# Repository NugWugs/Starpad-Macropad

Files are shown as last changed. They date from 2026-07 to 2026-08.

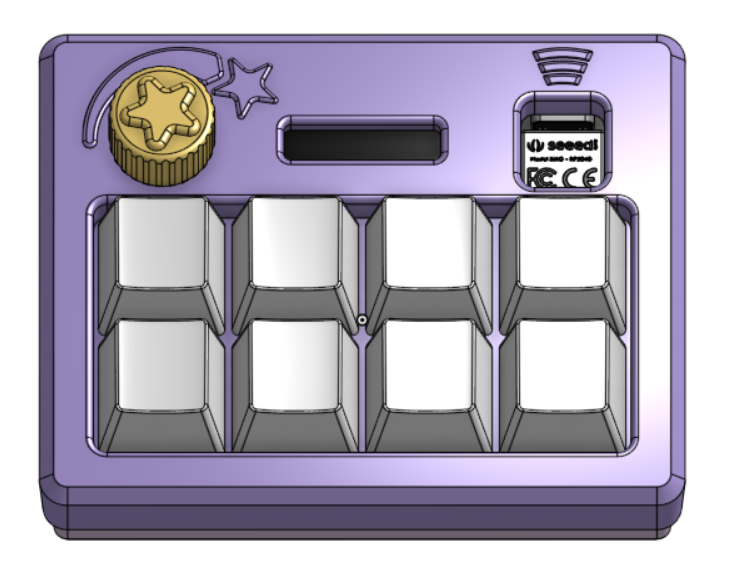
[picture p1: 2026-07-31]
starpad_v1/assets/img.png

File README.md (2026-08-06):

## Components:
- 4x2 Macropad Layout
- 1 Encoder Switch
- 1 0.91" 128x32 OLED Display
- Seeed Studio XIAO RP2040

## Function:
- Keys are programmed to hotkeys for different purposes
- Rotation of encoder changes volume
- Pressing of encoder switches between sets of hotkeys
- OLED displays selected hotkey set

## Onshape Link (CAD): 
https://cad.onshape.com/documents/8be66bb81c9edfabe40a1824/w/8ff97f5b07f3c9e6564f80fb/e/1183bdaa753b085b3b18a6f9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

## CAD:

<p align="left">
  isometric
  top
</p>

## PCB:
<p align="left">
  schematic
  pcb_routing
  pcb_top
</p>

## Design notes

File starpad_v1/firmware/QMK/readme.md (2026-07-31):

# XIAO RP2040 Macropad (QMK)

Custom QMK keyboard for a Seeed XIAO RP2040 driving a 4x2 button matrix
(SW1-SW8), a rotary encoder + push-switch (SW12), and an SSD1306 0.91"
128x32 I2C OLED (U2).

## Pin map (from schematic, D-number -> GPIO)

| Signal | XIAO pin | GPIO  |
|---|---|---|
| Col1 | D0 | GP26  |
| Col2 | D1 | GP27  |
| Col3 | D2 | GP28  |
| Col4 | D3 | GP29  |
| Row1 | D8 | GP2 |
| Row2 | D7 | GP1 |
| RotA | D9 | GP4 |
| RotB | D10 | GP3 |
| RotEnc | D6 | GP0 |
| SDA | D4 | GP6 |
| SCL | D5 | GP7 |

## Why a custom matrix.c

The schematic's diodes conduct **column -> row** (anode at the switch,
cathode toward the row net). QMK's stock `COL2ROW` scanner assumes the
opposite electrical polarity (idle-HIGH columns pulled briefly LOW,
rows pulled up and read LOW-for-pressed). To match your actual wiring,
`matrix.c` drives columns idle-LOW / active-HIGH and reads rows as
pulled-down / HIGH-for-pressed.

It also reads the encoder's push-switch (a plain switch-to-GND, no
diode) as a 9th key at matrix position `(row 2, col 0)`. Columns 1-3 of
row 2 don't physically exist and are left unmapped (`KC_NO` in the
keymap, though the default keymap only defines `KC_MUTE` at that one
real position).

**Double-check on the bench**: if the 8 main keys don't respond, or
respond only while held opposite of expected, the diode reading may be
backwards from what's on your schematic — flip the row read logic in
`matrix_scan_custom()` (swap `HIGH`/pull-down for `LOW`/pull-up) to
match.

## Build & flash

1. Drop this whole `xiao_rp2040_macropad` folder into
   `qmk_firmware/keyboards/`.
2. From the `qmk_firmware` root:
   ```
   qmk compile -kb xiao_rp2040_macropad -km default
   ```
3. Put the XIAO RP2040 into bootloader mode (double-tap the RESET
   button, or hold BOOTSEL while plugging in) — it will mount as a USB
   drive named `RPI-RP2`.
4. Copy the generated `.uf2` file (in
   `qmk_firmware/.build/`) onto that drive. The board reboots
   automatically running the new firmware.

## Customizing

- **Keymap**: edit `keymaps/default/keymap.c` — swap `KC_1`..`KC_8` for
  whatever keycodes/macros you actually want.
- **Encoder action**: `encoder_update_user()` in the same file currently
  does volume up/down; change it to anything else (media, custom
  layers, RGB, etc).
- **OLED content**: `oled_task_user()` currently just prints a static
  label — replace with layer indicators, WPM, encoder value, etc.

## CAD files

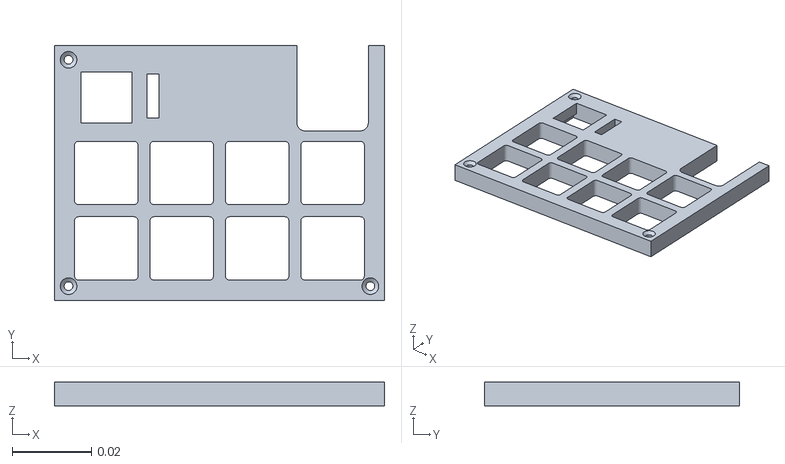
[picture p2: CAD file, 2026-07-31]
starpad_v1/production/pcb_cover.stl
0.0833 x 0.0643 x 0.006

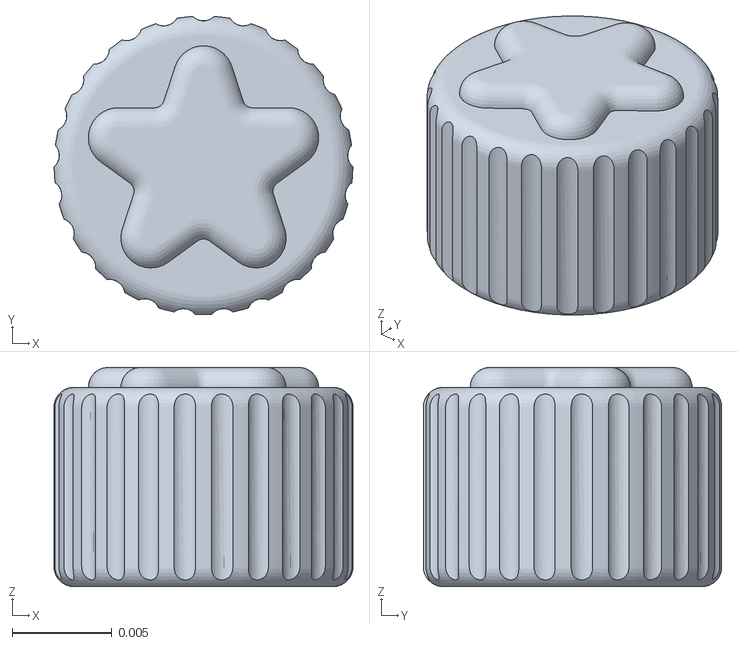
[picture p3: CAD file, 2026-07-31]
starpad_v1/production/star_knob.stl
0.015 x 0.015 x 0.011

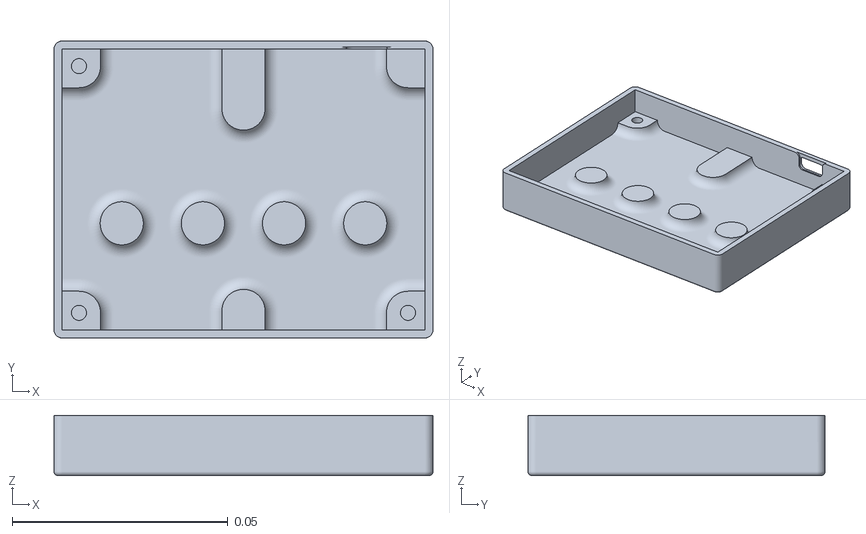
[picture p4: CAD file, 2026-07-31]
starpad_v1/production/bottom_case.stl
0.0878 x 0.0688 x 0.014

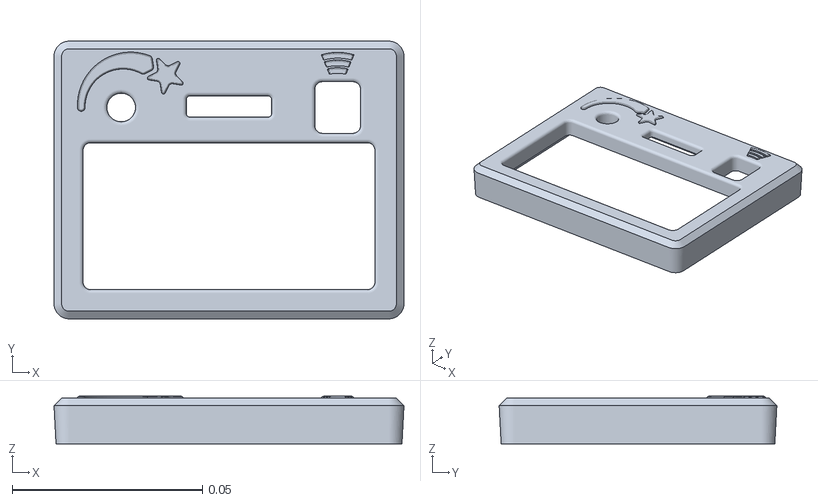
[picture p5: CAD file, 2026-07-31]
starpad_v1/production/top_case.stl
0.092 x 0.073 x 0.0125

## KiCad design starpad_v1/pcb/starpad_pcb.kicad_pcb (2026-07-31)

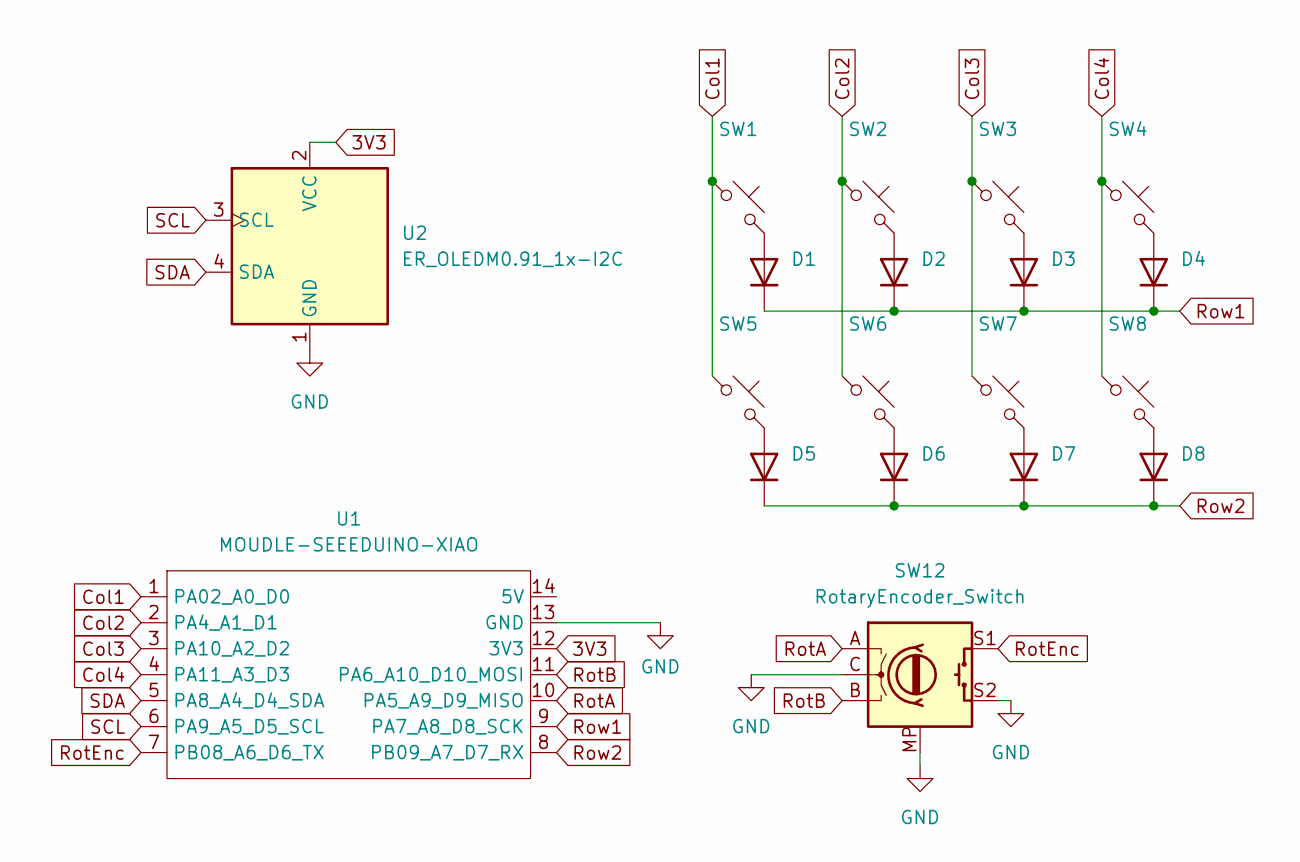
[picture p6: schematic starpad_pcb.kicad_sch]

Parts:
D1, D2, D3, D4, D5, D6, D7, D8: 1N914; D_DO-35_SOD27_P7.62mm_Horizontal
SW1, SW2, SW3, SW4, SW5, SW6, SW7, SW8: SW_Push_45deg; MX_PCB_1.00u
SW12: RotaryEncoder_Switch; RotaryEncoder_Alps_EC11E-Switch_Vertical_H20mm
U1: MOUDLE-SEEEDUINO-XIAO; XIAO-Generic-Hybrid-14P-2.54-21X17.8MM
U2: ER_OLEDM0.91_1x-I2C; SSD1306-0.91-OLED-4pin-128x32

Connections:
3V3: U1.12 (3V3), U2.2 (VCC)
Col1: SW1.1, SW5.1, U1.1 (PA02_A0_D0)
Col2: SW2.1, SW6.1, U1.2 (PA4_A1_D1)
Col3: SW3.1, SW7.1, U1.3 (PA10_A2_D2)
Col4: SW4.1, SW8.1, U1.4 (PA11_A3_D3)
GND: SW12.C, SW12.MP, SW12.S2, U1.13 (GND), U2.1 (GND)
unnamed: D1.2 (A), SW1.2
unnamed: D2.2 (A), SW2.2
unnamed: D3.2 (A), SW3.2
unnamed: D4.2 (A), SW4.2
unnamed: D5.2 (A), SW5.2
unnamed: D6.2 (A), SW6.2
unnamed: D7.2 (A), SW7.2
unnamed: D8.2 (A), SW8.2
RotA: SW12.A, U1.10 (PA5_A9_D9_MISO)
RotB: SW12.B, U1.11 (PA6_A10_D10_MOSI)
RotEnc: SW12.S1, U1.7 (PB08_A6_D6_TX)
Row1: D1.1 (K), D2.1 (K), D3.1 (K), D4.1 (K), U1.9 (PA7_A8_D8_SCK)
Row2: D5.1 (K), D6.1 (K), D7.1 (K), D8.1 (K), U1.8 (PB09_A7_D7_RX)
SCL: U1.6 (PA9_A5_D5_SCL), U2.3 (SCL)
SDA: U1.5 (PA8_A4_D4_SDA), U2.4 (SDA)

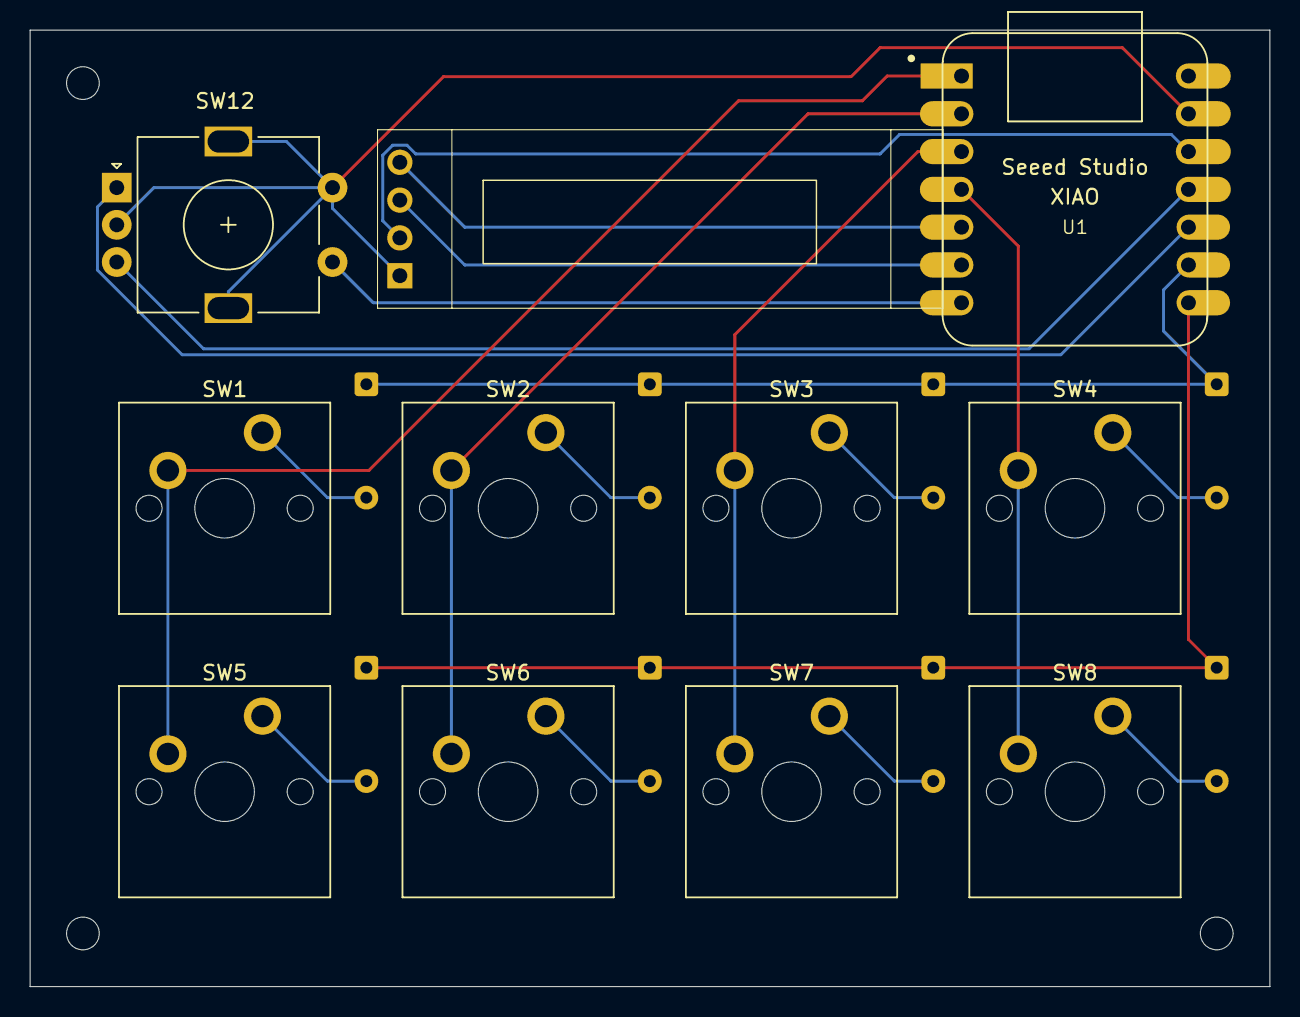
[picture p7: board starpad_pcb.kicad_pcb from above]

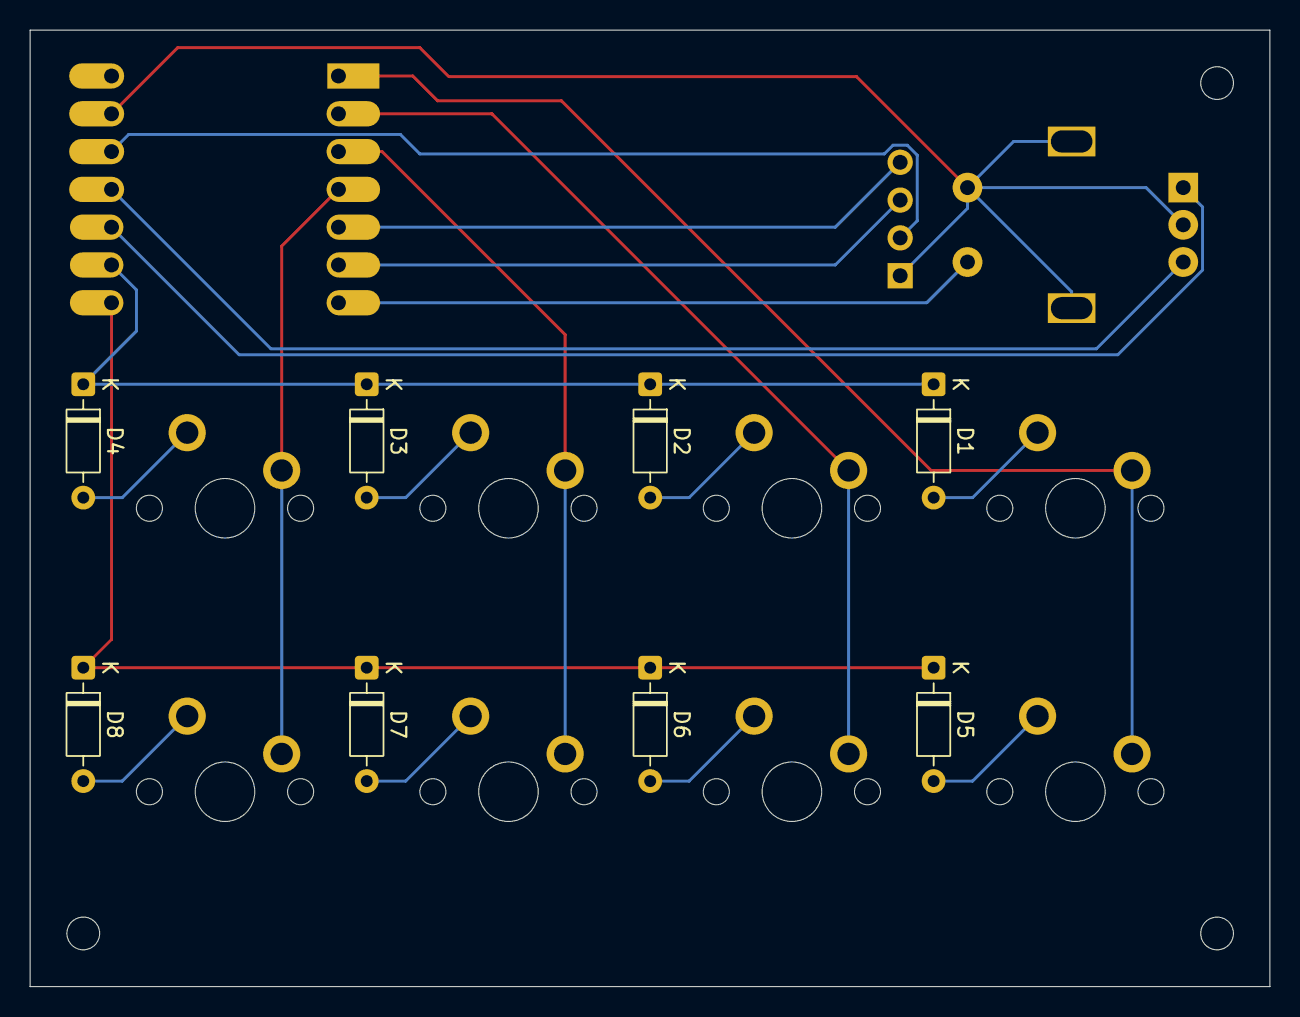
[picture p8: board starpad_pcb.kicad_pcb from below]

Board: 2 copper layers, 83.3 x 64.3 mm, 19 parts (8 on the bottom side), 21 nets.

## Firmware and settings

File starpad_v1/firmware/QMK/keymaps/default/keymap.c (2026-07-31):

#include QMK_KEYBOARD_H

// The encoder's push-switch (SW12) is a bare switch to GND on GP0 with no
// diode, so it can't live in the key matrix. We read it directly here.
#define ENC_SW_PIN GP0

const uint16_t PROGMEM keymaps[][MATRIX_ROWS][MATRIX_COLS] = {
    [0] = LAYOUT(
        KC_1,    KC_2,    KC_3,    KC_4,
        KC_5,    KC_6,    KC_7,    KC_8
    ),
};

void keyboard_pre_init_user(void) {
    // Switch-to-GND button: enable the internal pull-up so it idles HIGH
    // and reads LOW when pressed.
    gpio_set_pin_input_high(ENC_SW_PIN);
}

// Read the encoder push-switch every scan and tap KC_MUTE on each press.
// The matrix debounce.c doesn't cover this pin, so we do a small time-guard
// debounce ourselves (DEBOUNCE ms, same window the matrix uses).
void matrix_scan_user(void) {
    static bool     pressed     = false;
    static uint16_t last_change = 0;

    bool now = !gpio_read_pin(ENC_SW_PIN); // active-low: LOW = pressed
    if (now != pressed && timer_elapsed(last_change) > DEBOUNCE) {
        pressed     = now;
        last_change = timer_read();
        if (pressed) {
            tap_code(KC_MUTE);
        }
    }
}

bool encoder_update_user(uint8_t index, bool clockwise) {
    if (index == 0) {
        if (clockwise) {
            tap_code(KC_VOLU);
        } else {
            tap_code(KC_VOLD);
        }
    }
    return false;
}

#ifdef OLED_ENABLE
bool oled_task_user(void) {
    oled_write_P(PSTR("Macropad\n"), false);
    oled_write_P(PSTR("8 keys + enc\n"), false);
    return false;
}
#endif
